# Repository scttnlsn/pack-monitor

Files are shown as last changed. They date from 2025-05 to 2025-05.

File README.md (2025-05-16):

# pack-monitor

Communicates with 1 or more [cell-monitor](https://github.com/scttnlsn/cell-monitor)s to monitor and
protect a battery pack.

## System Setup (Linux)

```
sudo apt update
sudo apt install cmake gcc-arm-none-eabi libnewlib-arm-none-eabi build-essential g++ libstdc++-arm-none-eabi-newlib
```

## SDK Setup

```
git clone https://github.com/raspberrypi/pico-sdk.git --branch master
cd pico-sdk
git submodule update --init
cd ..
export PICO_SDK_PATH=$(pwd)/pico-sdk
```

## Build

```
mkdir build
cd build
cmake ..
make -j4
```

## References

Pico:

* https://datasheets.raspberrypi.org/pico/Pico-R3-A4-Pinout.pdf
* https://datasheets.raspberrypi.org/rp2040/rp2040-datasheet.pdf
* https://datasheets.raspberrypi.org/pico/raspberry-pi-pico-c-sdk.pdf
* https://raspberrypi.github.io/pico-sdk-doxygen/

Modbus:

* https://www.fernhillsoftware.com/help/drivers/modbus/modbus-protocol.html
* https://minimalmodbus.readthedocs.io/en/stable/modbusdetails.html

Onewire:

* https://www.maximintegrated.com/en/design/technical-documents/app-notes/1/126.html

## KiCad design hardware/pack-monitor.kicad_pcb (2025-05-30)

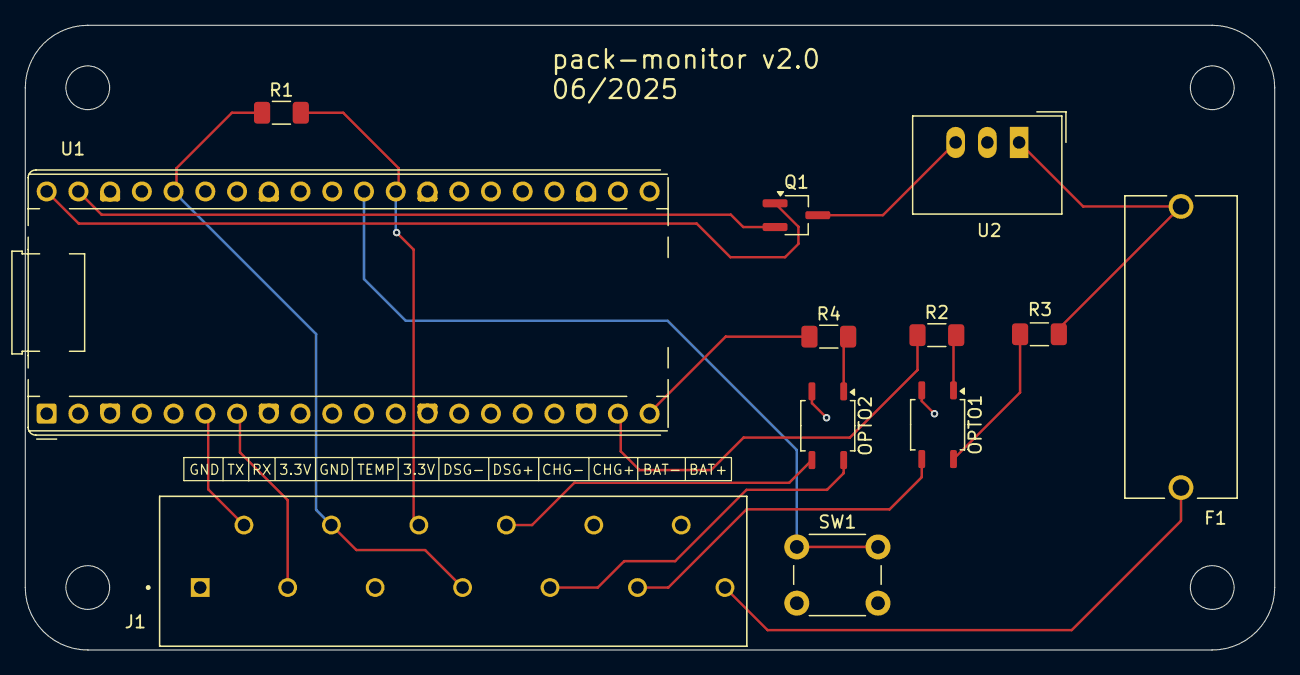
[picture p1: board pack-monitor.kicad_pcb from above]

Board: 2 copper layers, 100.0 x 50.0 mm, 12 parts (0 on the bottom side), 19 nets.

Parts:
F1: 4628; FUSE_4628
J1: 1985302; PHOENIX_1985302
OPTO1, OPTO2: SSR; SOP-4_3.8x4.1mm_P2.54mm
Q1: PMOS; TSOT-23_HandSoldering
R1: 4.7k; R_1206_3216Metric_Pad1.30x1.75mm_HandSolder
R2, R3, R4: 1k; R_1206_3216Metric_Pad1.30x1.75mm_HandSolder
SW1: RESET_BTN; SW_PUSH_6mm
U1: Pico; RaspberryPi_Pico_Common_THT
U2: TSR 0.5-2450; Converter_DCDC_TRACO_TSR-1_THT

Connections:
+3.3V: J1.4, J1.7, R1.1, U1.36 (3V3)
+BATT: F1.1, J1.13
/BATT_V: F1.2, R3.1, U2.1 (IN)
/CELLS_RX: J1.3, U1.7 (GPIO5)
/CELLS_TX: J1.2, U1.6 (GPIO4)
/CHG: R2.1, U1.19 (GPIO14)
/CHG+: J1.11, OPTO1.3
/DSG: R4.1, U1.20 (GPIO15)
/DSG+: J1.9, OPTO2.4
/DSG-: J1.8, OPTO2.3
/RESET: SW1.1, U1.30 (RUN)
/TEMP: J1.6, R1.2, U1.29 (GPIO22)
/VBUS: Q1.1 (G), U1.40 (VBUS)
/VSYS: Q1.2 (S), U1.39 (VSYS)
GND: J1.1, J1.5, J1.10, J1.12, OPTO1.2, OPTO2.2, SW1.2, U1.3 (GND), U1.8 (GND), U1.13 (GND), U1.18 (GND), U1.23 (GND), U1.28 (GND), U1.33 (AGND), U1.38 (GND), U2.2 (GND)
unnamed: OPTO1.1, R2.2
unnamed: OPTO1.4, R3.2
unnamed: OPTO2.1, R4.2
unnamed: Q1.3 (D), U2.3 (OUT)

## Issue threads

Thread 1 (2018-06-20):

Enable watchdog timer

scttnlsn, 2018-06-20:
Reset the device if the watchdog expires

scttnlsn, 2018-07-16:
https://github.com/scttnlsn/charge-controller/commit/4c96fef1e3d1018af1bbdde778533b1c0eff9ca0

Closed 2018-07-16.

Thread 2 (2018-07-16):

Persist SOC to EEPROM

scttnlsn, 2018-07-16:
When the device is reset we don't know the state of charge.  Currently we assume 100% but cannot know the true SOC until the over-voltage limit is hit.  Would be nice to keep this value persistent.

Closed 2025-05-16.

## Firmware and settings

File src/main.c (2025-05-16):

#include <stdio.h>
#include <stddef.h>
#include <string.h>
#include "pico/stdlib.h"
#include "pico/util/queue.h"
#include "hardware/exception.h"
#include "pico/time.h"
#include "hardware/watchdog.h"

#include "config.h"
#include "events.h"
#include "led.h"
#include "modbus.h"
#include "onewire.h"
#include "temp.h"
#include "cell_monitors.h"
#include "registers.h"
#include "protection.h"

registers_t registers;
onewire_t onewire = { .pin = ONEWIRE_PIN };
modbus_t modbus;
cell_monitors_t cell_monitors;
repeating_timer_t timer;
temp_t temp;

static void handle_connected();
static void handle_disconnected();
static void handle_interval();
static void handle_register_updated();
static void handle_cell_updated();

bool timer_callback(repeating_timer_t *rt) {
  event_t event = {
    .event_type = EVENT_TYPE_INTERVAL,
  };
  events_enqueue(event);

  // keep repeating
  return true;
}

void isr_hardfault() {
  watchdog_disable();

  while (1) {
    led_blink();
    led_blink();
    led_blink();
    sleep_ms(1000);
  }
}

void connect() {
  led_pulse_start();
  if (!cell_monitors_connect(&cell_monitors)) {
    // could not enqueue connection request
    registers.errors |= ERROR_FAULT;
    led_pulse_stop();
  } else {
    registers.status |= STATUS_CONNECTING;
  }
}

int main() {
  watchdog_enable(3000, false);
  exception_set_exclusive_handler(HARDFAULT_EXCEPTION, isr_hardfault);

  if (watchdog_caused_reboot()) {
    registers.errors |= ERROR_WATCHDOG;
  }

  protection_init();
  
  stdio_init_all();
  // we're sending binary data over stdio
  stdio_set_translate_crlf(&stdio_usb, false);

  events_init();
  led_init();
  onewire_init(&onewire);
  temp_init(&temp, &onewire);

  memset(&registers, 0, sizeof(registers_t));
  registers.version = 1;
  
  modbus_init(&modbus);
  modbus.unit_address = 1;
  modbus.registers = (uint16_t *)&registers;
  modbus.num_registers = sizeof(registers) / sizeof(uint16_t);

  cell_monitors_init(
    &cell_monitors,
    uart1,
    CELL_MONITORS_UART_RX_PIN,
    CELL_MONITORS_UART_TX_PIN
  );

  add_repeating_timer_ms(
    CELL_MONITORS_INTERVAL,
    timer_callback,
    NULL,
    &timer
  );

  connect();

  // main loop
  while (true) {
    watchdog_update();

    // process any events from the queue
    event_t event;
    while (events_dequeue(&event)) {
      switch (event.event_type) {
        case EVENT_TYPE_CONNECTED:
          handle_connected(&event);
          break;
        case EVENT_TYPE_DISCONNECTED:
          handle_disconnected(&event);
          break;
        case EVENT_TYPE_INTERVAL:
          handle_interval(&event);
          break;
        case EVENT_TYPE_REGISTER_UPDATED:
          handle_register_updated(&event);
          break;
        case EVENT_TYPE_CELL_UPDATED:
          handle_cell_updated(&event);
          break;
      }
    }

    // update various sub-systems
    cell_monitors_update(&cell_monitors);
    protection_update(&registers);
    modbus_update(&modbus);

    temp_result_t temp_result;
    if (temp_update(&temp, &temp_result)) {
      registers.temp_upper = temp_result.upper;
      registers.temp_lower = temp_result.lower;
    }

    // update registers
    if (cell_monitors.connected) {
      if (cell_monitors.current_request.error) {
        if (cell_monitors.current_request.error & CELL_MONITORS_ERROR_CRC) {
          registers.errors |= ERROR_CRC;
        } else {
          registers.errors &= ~ERROR_CRC;
        }

        if (cell_monitors.current_request.error & CELL_MONITORS_ERROR_TIMEOUT) {
          registers.errors |= ERROR_TIMEOUT;
        } else {
          registers.errors &= ~ERROR_TIMEOUT;
        }

        if (cell_monitors.current_request.error & CELL_MONITORS_ERROR_NO_RESPONSE) {
          registers.errors |= ERROR_NO_RESPONSE;
        } else {
          registers.errors &= ~ERROR_NO_RESPONSE;
        }
      }
    }

    if (modbus.error) {
      registers.errors |= ERROR_MODBUS;
    } else {
      registers.errors &= ~ERROR_MODBUS;
    }

    sleep_ms(10);
  }
}

// event handlers

static void handle_connected(event_t *event) {
  led_pulse_stop();
  registers.status |= STATUS_CONNECTED;
  registers.status &= ~STATUS_CONNECTING;
  registers.num_cells = cell_monitors.num_cells;
}

static void handle_disconnected(event_t *event) {
  registers.status &= ~STATUS_CONNECTED;
  for (int i = 0; i < registers.num_cells; i++) {
    registers.cell_voltages[i] = 0;
  }

  connect();
}

static void handle_interval(event_t *event) {
  if (!cell_monitors.connected) {
    return;
  }

  // 2 blinks signals the start of a measurement cycle
  led_blink();
  led_blink();

  // enqueue voltage read request for each cell
  uint8_t num_cells = cell_monitors.num_cells;
  for (uint8_t cell_address = 1; cell_address <= num_cells; cell_address++) {
    cell_monitors_read(
        &cell_monitors,
        cell_address,
        CELL_MONITORS_REG_VOLTAGE
    );
  }

  // start new temp read
  if (!temp.waiting) {
    temp_start_read(&temp);
  }
}

static void handle_register_updated(event_t *event) {
  // a register was written - we may need to write the update to the cell monitors
  uint16_t reg = event->reg_info.reg;
  uint16_t previous_value = event->reg_info.previous_value;
  uint16_t current_value = event->reg_info.current_value;

  // offsetof returns bytes so we divide by 2
  uint16_t offset = offsetof(registers_t, cell_voltages) / 2;

  if (offset <= reg && reg < offset + MAX_CELLS) {
    // a cell voltage reference was updated
    uint16_t cell_offset = reg - offset;
    uint16_t cell_address = cell_offset + 1;
    uint16_t cell_voltage = registers.cell_voltages[cell_offset];

    cell_monitors_write(
      &cell_monitors,
      cell_address,
      CELL_MONITORS_REG_VOLTAGE,
      cell_voltage
    );
  }
}

static void handle_cell_updated(event_t *event) {
  // cell state was updated
  uint8_t cell_address = event->cell_address;

  uint8_t cell_index = cell_address - 1;
  registers.cell_voltages[cell_index] = cell_monitors.cell_states[cell_index].voltage;

  absolute_time_t sent_at = cell_monitors.current_request.sent_at;
  absolute_time_t received_at = cell_monitors.current_request.received_at;
  registers.round_trip_time = (uint16_t)absolute_time_diff_us(sent_at, received_at) / (uint16_t)1000;

  // 1 blink indicates 1 measurement received
  led_blink();
}

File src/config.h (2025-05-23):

#ifndef __CONFIG_H__
#define __CONFIG_H__

#define DEBUG false

#define ONEWIRE_PIN 22
#define CELL_MONITORS_UART_TX_PIN 4
#define CELL_MONITORS_UART_RX_PIN 5

#define CELL_MONITORS_INTERVAL 5000
#define CONNECT_TIMEOUT 10000
#define REQUEST_TIMEOUT 2000

#define CHARGE_CUTOFF_TEMP 8 // ~46F

#define PROTECTION_CHG_PIN 14
#define PROTECTION_DSG_PIN 15
#define PROTECTION_OV_ENABLE 3550
#define PROTECTION_OV_DISABLE 3350
#define PROTECTION_UV_ENABLE 3000
#define PROTECTION_UV_DISABLE 3100

#endif

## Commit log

2018-05-22 Cell voltage monitoring, protection checks
2018-05-30 Added current measurements and calibration
2018-07-06 Short delay before zeroing current
2018-07-16 Move pack voltage divider to config file
2018-08-09 Fix pack voltage divider
    [config.h]
2018-08-11 Move max voltage error to config file
    [config.h]
2018-08-27 Added charge and discharge coulomb counting
2018-10-10 Added error timeout before fault is triggered
    [config.h]
2021-02-05 Initial pico setup
2021-02-09 Added onewire and ds18b20 drivers
2024-09-20 Gracefully handle cell monitor disconnection/error
    [cell_monitors.c, led.c, main.c]
2024-09-27 Cell monitor calibration through modbus interface
2025-04-14 Expose status, protection and error in registers
    [cell_monitors.c, client.py, main.c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]
2025-05-09 Fix decoding write bit
    [cell_monitors.c]
2025-05-16 More error handling, remove voltage_ref registers
    [cell_monitors.c, main.c]
2025-05-16 Update client script, add calibration script
2025-05-23 Add KiCad files
    [pack-monitor.kicad_pcb, pack-monitor.kicad_sch]
2025-05-30 Update pmos pins
    [pack-monitor.kicad_pcb, pack-monitor.kicad_sch]
